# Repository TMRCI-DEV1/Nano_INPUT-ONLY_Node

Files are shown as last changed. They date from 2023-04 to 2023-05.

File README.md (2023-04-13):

# Nano_INPUT-ONLY_Node
Arduino Nano-based input only Node
capture-2023-02-14T20_02_11 532Z

Shield: [][cc-by-sa]

This work is licensed under a
[Creative Commons Attribution-ShareAlike 4.0 International License][cc-by-sa].

[][cc-by-sa]

[cc-by-sa]: http://creativecommons.org/licenses/by-sa/4.0/
[cc-by-sa-image]: https://licensebuttons.net/l/by-sa/4.0/88x31.png
[cc-by-sa-shield]: https://img.shields.io/badge/License-CC%20BY--SA%204.0-lightgrey.svg

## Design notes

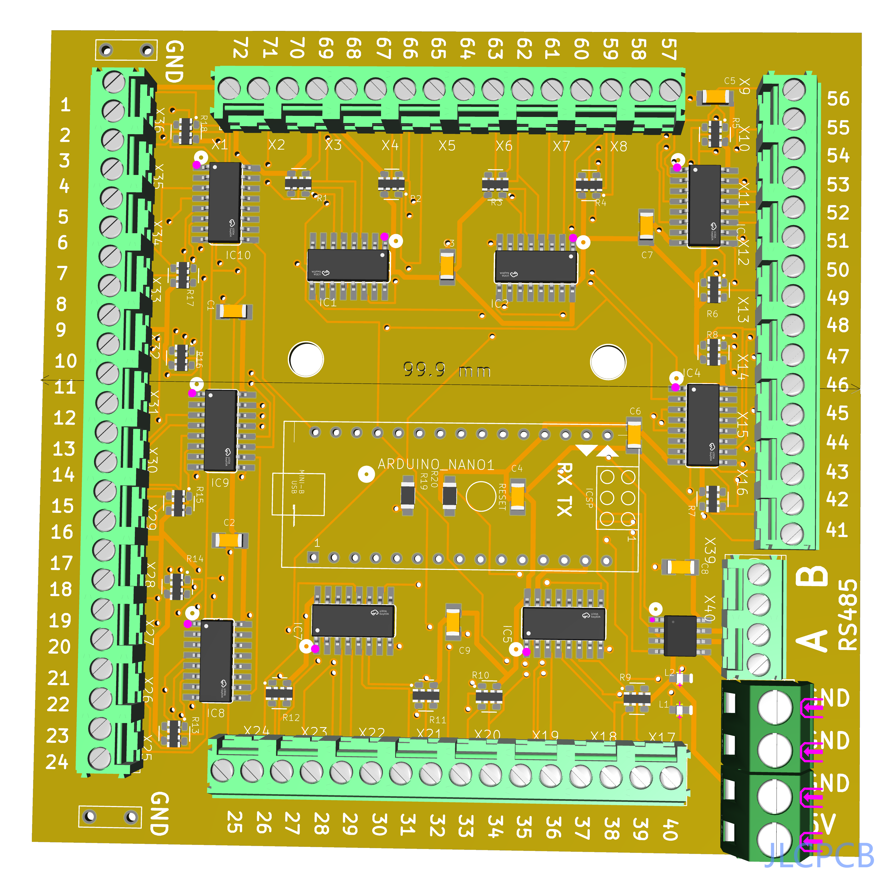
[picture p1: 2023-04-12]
KiCad/3D_Models/capture-2023-02-14T20_02_11.532Z.png

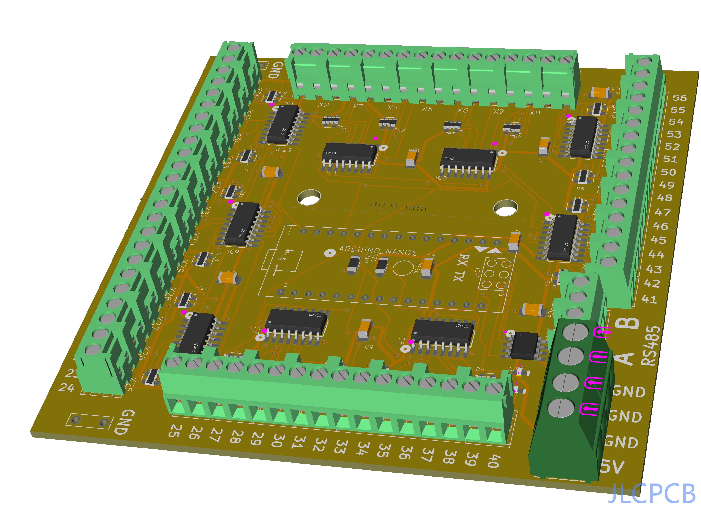
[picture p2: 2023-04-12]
KiCad/3D_Models/capture-2023-02-14T20_02_35.878Z.png

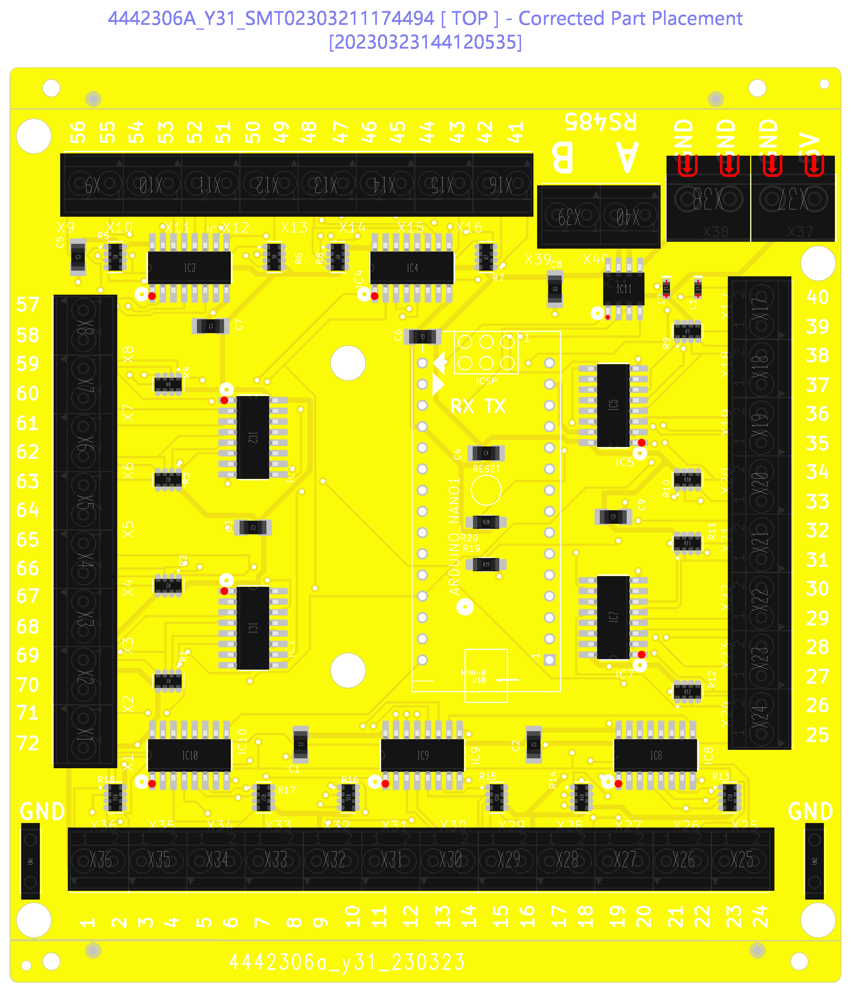
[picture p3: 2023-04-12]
KiCad/3D_Models/Produce_DanZhi.SMT_Snapshot.Top.4442306A_Y31.SMT02303211174494.png

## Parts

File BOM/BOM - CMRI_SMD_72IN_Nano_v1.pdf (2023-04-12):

Designators | Value | Footprint | Manufacturer Part Number | Quantity
C1, C2, C3, C4, C5, C6, C7, C8, C9 | 100nF | 1206 | CL31B104KBCNNNC | 9
R1, R2, R3, R4, R5, R6, R7, R8, R9, R10, R11, R12, R13, R14, R15, R16, R17, R18 | 10k | 0603 | 742C083103JP | 18 | OR USE: | RTA03-4D103JTP (https://jlcpcb.com/partdetail/Ralec-RTA034D103JTP/C102646)
R19, R20 | 1k | 1206 | 1206W4F1001T5 | 2

X1, X2, X3, X4, X5, X6, X7, X8, X9, X10, X11, X12, X13, X14, X15, X16, X17, X18, X19, X20,
X21, X22, X23, X24, X25, X26, X27, X28, X29, X30, X31, X32, X33, X34, X35, X36, X39, X40 TERMINAL_7.5X7.3MM_TM | TERMINAL_7.5X7.3MM_TM | KF350-3.5-2P | 38
X37, X38 | TERMINAL_10.16X8.1MM_TM | TERMINAL_10.16X8.1MM_TM WJ128V-5.0-2P | 2
IC1, IC2, IC3, IC4, IC5, IC7, IC8, IC9, IC10 | 74HC165D, 653 | SOIC16_150MIL | 74HC165D,653 | 9
H1, H2 | MOUNT-HOLE4.1 | 4,1 | | 2 | DNP
ARDUINO_NANO1 | | ARDUINO_NANO_HEADERS | 15Fx1-254mm | 2 | DNP | 15Fx1-254mm (https://www.electromaker.io/shop/product/254mm-01-15-pin-female-header)
IC11 | MAX485 | SOP8 | MAX485ED | 1
U$1, U$2 | Quick connect terminal Plugin | LUG-5MM | JNQ023 | 2 | | JNQ023 (https://www.lcsc.com/product-detail/Cold-pressed-Terminals_Temile-JNQ023_C499663.html)
L2 | Vcc，CHIPLED_0603, red | 0603 | LTST-C190KRKT | 1
L1 | Status，CHIPLED_0603, yellow | 0603 | LTST-C190KSKT | 1

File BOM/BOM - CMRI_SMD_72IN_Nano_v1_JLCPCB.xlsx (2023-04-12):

Comment | Designator | Footprint | JLCPCB Part #
Status，CHIPLED_0603, yellow | L1 | 0603 | C125095
100nF | C1,C2,C3,C4,C5,C6,C7,C8,C9 | 1206 | C24497
MAX485，SO08 | IC11 | SOP8 | C481667
10k | R1, R2, R3, R4, R5, R6, R7, R8, R9, R10, R11, R12, R13, R14, R15, R16, R17, R18 | 0603 | C102646 | C192513 | C2654027
74HC165D | IC1, IC2, IC3, IC4, IC5, IC7, IC8, IC9, IC10 | SOIC16_150MIL | C5613
TERMINAL_7.5X7.3MM_TM | X1,X2,X3,X4,X5,X6,X7,X8,X9,X10,X11,X12,X13,X14,X15,X16,X17,X18,X19,X20,X21,X22,X23,X24,X25,X26,X27,X28,X29,X30,X31,X32,X33,X34,X35,X36,X39,X40 | KF350-3.5-2P | C474892
Vcc，CHIPLED_0603, red | L2 | 0603 | C94869
1k | R19, R20 | 1206 | C4410
QUICK CONNECT TERMINAL | U$1,U$2 | PLUGIN | C499663
TERMINAL_10.16X8.1MM_TM | X37,X38 | TERMINAL_10.16X8.1MM_TM | C8269

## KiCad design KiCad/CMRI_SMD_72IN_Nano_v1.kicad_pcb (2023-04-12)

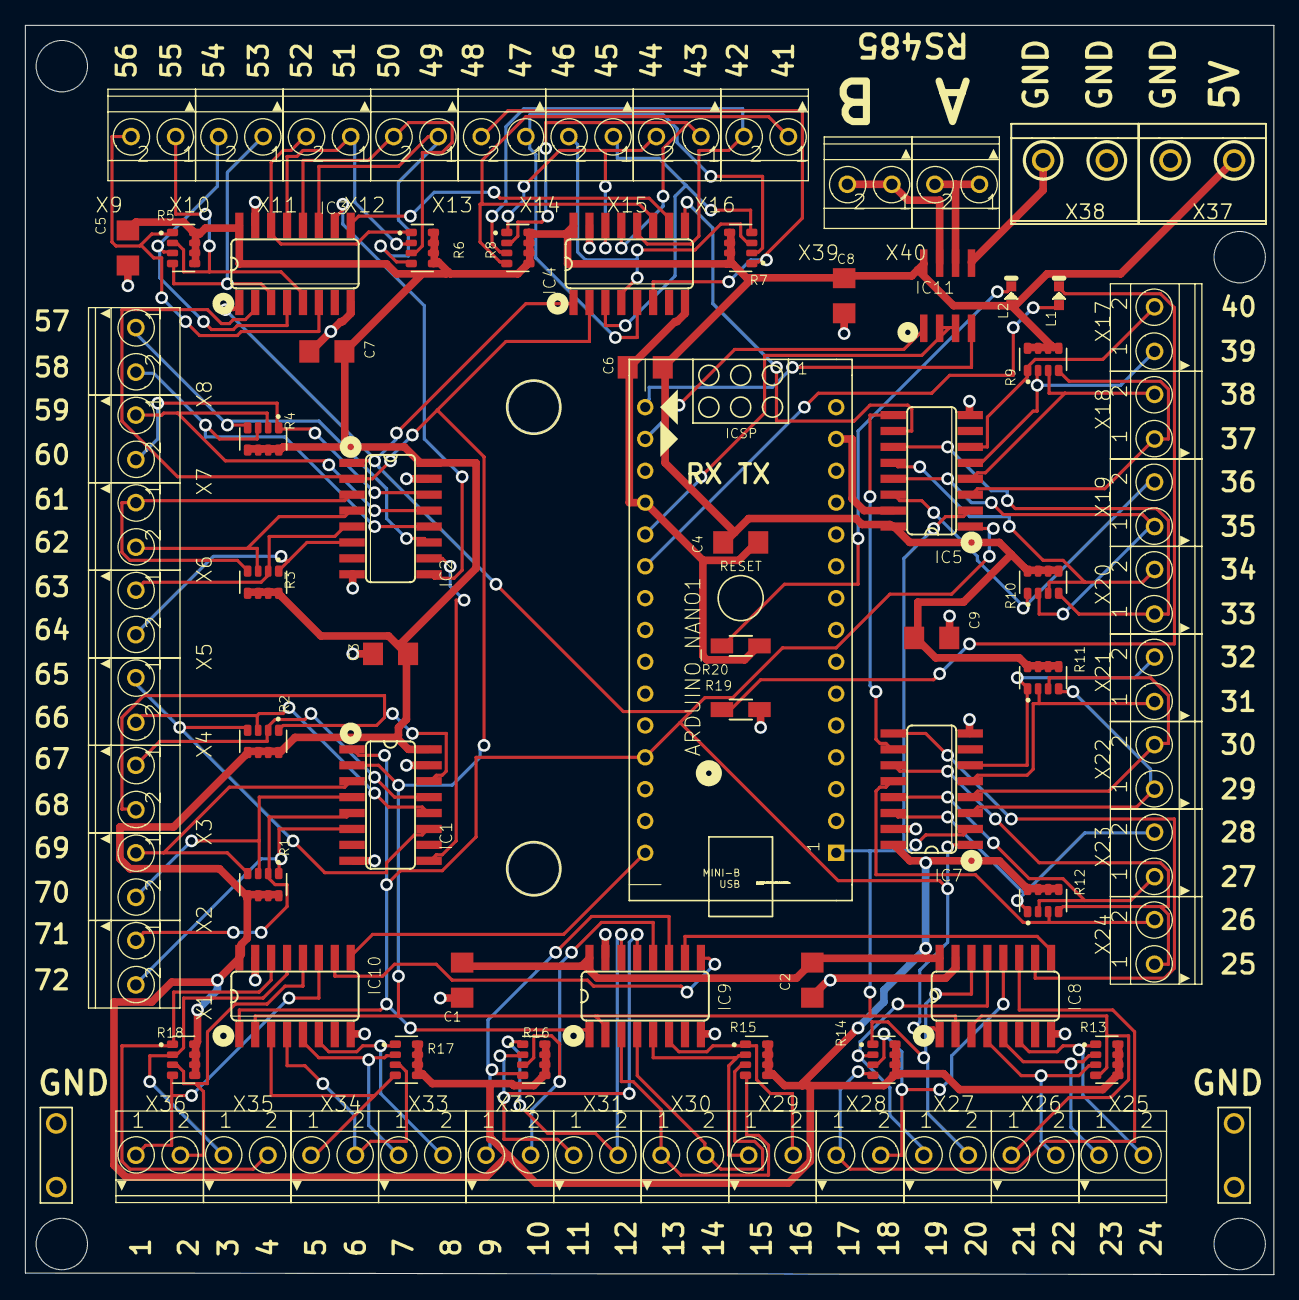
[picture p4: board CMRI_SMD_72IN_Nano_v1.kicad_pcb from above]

Board: 2 copper layers, 99.6 x 99.7 mm, 86 parts (0 on the bottom side), 93 nets.

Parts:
ARDUINO_NANO1: ARDUINO_NANO
C1, C2, C3, C4, C5, C6, C7, C8, C9: 100nF; 1206
H1, H2: MOUNT-HOLE4.1; 4,1
IC1, IC2, IC3, IC4, IC5, IC7, IC8, IC9, IC10: 74HC165D; SO16
IC11: MAX485; SO08
L1: STATUS; LED-0603
L2: Vcc; LED-0603
R1, R2, R3, R4, R5, R6, R7, R8, R9, R10, R11, R12, R13, R14, R15, R16, R17, R18: 10k; RESISTORARRAY-0603
R19, R20: 1k; R1206W
U$1, U$2: LUG-5MM
X1, X2, X3, X4, X5, X6, X7, X8, X9, X10, X11, X12, X13, X14, X15, X16, X17, X18, X19, X20, X21, X22, X23, X24, X25, X26, X27, X28, X29, X30, X31, X32, X33, X34, X35, X36, X39, X40: TERMINAL_2P_3,5MM_V2
X37, X38: W237-132

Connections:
A: IC11.6, X40.P$1, X40.P$2
B: IC11.7, X39.P$1, X39.P$2
D3: ARDUINO_NANO1.21, L1.A
GND: ARDUINO_NANO1.14, ARDUINO_NANO1.19, C1.1, C2.1, C3.1, C4.1, C5.1, C6.1, C7.1, C8.1, C9.1, IC1.8, IC1.15, IC2.8, IC2.15, IC3.8, IC3.15, IC4.8, IC4.15, IC5.8, IC5.15, IC7.8, IC7.15, IC8.8, IC8.15, IC9.8, IC9.15, IC10.8, IC10.15, IC11.5, R19.1, R20.1, U$1.P$3, U$1.P$4, U$2.P$3, U$2.P$4, X37.2, X38.1, X38.2
LATCH: ARDUINO_NANO1.27, IC1.1, IC2.1, IC3.1, IC4.1, IC5.1, IC7.1, IC8.1, IC9.1, IC10.1
unnamed: IC3.11, R6.4, X12.P$1
unnamed: IC1.9, IC2.10
unnamed: IC3.12, R6.3, X12.P$2
unnamed: IC2.9, IC3.10
unnamed: IC3.13, R6.2, X11.P$1
unnamed: IC4.11, R8.4, X16.P$1
unnamed: IC3.14, R6.1, X11.P$2
unnamed: IC4.12, R8.3, X16.P$2
unnamed: IC3.3, R5.4, X10.P$1
unnamed: IC4.13, R8.2, X15.P$1
unnamed: IC3.4, R5.3, X10.P$2
unnamed: IC4.14, R8.1, X15.P$2
unnamed: IC3.5, R5.2, X9.P$1
unnamed: IC4.3, R7.4, X14.P$1
unnamed: IC3.6, R5.1, X9.P$2
unnamed: IC4.4, R7.3, X14.P$2
unnamed: L1.C, R19.2
unnamed: IC4.5, R7.2, X13.P$1
unnamed: IC2.11, R4.4, X8.P$1
unnamed: IC4.6, R7.1, X13.P$2
unnamed: IC2.12, R4.3, X8.P$2
unnamed: IC3.9, IC4.10
unnamed: IC2.13, R4.2, X7.P$1
unnamed: IC5.11, R10.4, X20.P$1
unnamed: IC2.14, R4.1, X7.P$2
unnamed: IC5.12, R10.3, X20.P$2
unnamed: IC2.3, R3.4, X6.P$1
unnamed: IC5.13, R10.2, X19.P$1
unnamed: IC2.4, R3.3, X6.P$2
unnamed: IC5.14, R10.1, X19.P$2
unnamed: IC2.5, R3.2, X5.P$1
unnamed: IC5.3, R9.4, X18.P$1
unnamed: IC2.6, R3.1, X5.P$2
unnamed: IC5.4, R9.3, X18.P$2
unnamed: IC1.11, R2.4, X4.P$1
unnamed: IC5.5, R9.2, X17.P$1
unnamed: IC1.12, R2.3, X4.P$2
unnamed: IC5.6, R9.1, X17.P$2
unnamed: IC1.13, R2.2, X3.P$1
unnamed: IC4.9, IC5.10
unnamed: IC1.14, R2.1, X3.P$2
unnamed: IC7.11, R12.4, X24.P$1
unnamed: IC1.3, R1.4, X2.P$1
unnamed: IC7.12, R12.3, X24.P$2
unnamed: IC1.4, R1.3, X2.P$2
unnamed: IC7.13, R12.2, X23.P$1
unnamed: IC1.5, R1.2, X1.P$1
unnamed: IC7.14, R12.1, X23.P$2
unnamed: IC7.3, R11.4, X22.P$1
unnamed: IC7.4, R11.3, X22.P$2
unnamed: IC7.5, R11.2, X21.P$1
unnamed: IC7.6, R11.1, X21.P$2
unnamed: IC5.9, IC7.10
unnamed: L2.C, R20.2
unnamed: ARDUINO_NANO1.20, IC11.2, IC11.3
unnamed: IC8.11, R14.4, X28.P$1
unnamed: IC1.6, R1.1, X1.P$2
unnamed: IC8.12, R14.3, X28.P$2
unnamed: IC8.13, R14.2, X27.P$1
unnamed: IC8.14, R14.1, X27.P$2
unnamed: IC8.3, R13.4, X26.P$1
unnamed: IC8.4, R13.3, X26.P$2
unnamed: IC8.5, R13.2, X25.P$1
unnamed: IC8.6, R13.1, X25.P$2
unnamed: IC7.9, IC8.10
unnamed: IC9.11, R16.4, X32.P$1
unnamed: IC9.12, R16.3, X32.P$2
unnamed: IC9.13, R16.2, X31.P$1
unnamed: IC9.14, R16.1, X31.P$2
unnamed: IC9.3, R15.4, X30.P$1
unnamed: IC9.4, R15.3, X30.P$2
unnamed: IC9.5, R15.2, X29.P$1
unnamed: IC9.6, R15.1, X29.P$2
unnamed: IC8.9, IC9.10
unnamed: IC10.11, R18.4, X36.P$1
unnamed: IC10.12, R18.3, X36.P$2
unnamed: IC10.13, R18.2, X35.P$1
unnamed: IC10.14, R18.1, X35.P$2
unnamed: IC10.3, R17.4, X34.P$1
unnamed: IC10.4, R17.3, X34.P$2
unnamed: IC10.5, R17.2, X33.P$1
unnamed: IC10.6, R17.1, X33.P$2
unnamed: IC9.9, IC10.10
RX: ARDUINO_NANO1.17, IC11.1
SCK: ARDUINO_NANO1.1, IC1.2, IC2.2, IC3.2, IC4.2, IC5.2, IC7.2, IC8.2, IC9.2, IC10.2
SO: ARDUINO_NANO1.30, IC10.9
TX: ARDUINO_NANO1.16, IC11.4
VCC: C1.2, C2.2, C3.2, C4.2, C5.2, C6.2, C7.2, C8.2, C9.2, IC1.16, IC2.16, IC3.16, IC4.16, IC5.16, IC7.16, IC8.16, IC9.16, IC10.16, IC11.8, L2.A, R1.5, R1.6, R1.7, R1.8, R2.5, R2.6, R2.7, R2.8, R3.5, R3.6, R3.7, R3.8, R4.5, R4.6, R4.7, R4.8, R5.5, R5.6, R5.7, R5.8, R6.5, R6.6, R6.7, R6.8, R7.5, R7.6, R7.7, R7.8, R8.5, R8.6, R8.7, R8.8, R9.5, R9.6, R9.7, R9.8, R10.5, R10.6, R10.7, R10.8, R11.5, R11.6, R11.7, R11.8, R12.5, R12.6, R12.7, R12.8, R13.5, R13.6, R13.7, R13.8, R14.5, R14.6, R14.7, R14.8, R15.5, R15.6, R15.7, R15.8, R16.5, R16.6, R16.7, R16.8, R17.5, R17.6, R17.7, R17.8, R18.5, R18.6, R18.7, R18.8, X37.1

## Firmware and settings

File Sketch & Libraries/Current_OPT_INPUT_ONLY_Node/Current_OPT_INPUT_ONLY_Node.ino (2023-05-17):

/*
  Project: Arduino Nano-based CMRI Input-Only SUSIC Node (72 inputs)
  Author: Thomas Seitz (thomas.seitz@tmrci.org)
  Version: 1.0.2
  Date: 2023-05-17
  Description: A sketch for an Arduino Nano-based CMRI Input-Only custom SUSIC Node board using RS-485
*/

// Import required libraries
#include <Auto485.h>                                // Library for RS485 communication
#include <CMRI.h>                                   // Library for CMRI communication
#include <SPI.h>                                    // Library for SPI communication

const byte CMRI_ADDR = 5;                           // Define CMRI node address
const byte DE_PIN = 2;                              // Define RS485 DE and RE pins on Arduino
#define NOP __asm__ __volatile__("nop")             // "nop" assembly instruction macro

// Define pins for 74HC165
const byte LATCH_165 = 9;

Auto485 bus(DE_PIN);                                // Initialize RS485 bus transceiver
CMRI cmri(CMRI_ADDR, 72, 0, bus); // sets up a modified SMINI. 72 inputs, 0 outputs

byte last_input_state[9];                           // Define variable to store the previous state of inputs

void setup() {
  // Open the RS485 bus at 19200bps
  bus.begin(19200, SERIAL_8N2);

  // 74HC165 setup
  pinMode(LATCH_165, OUTPUT);
  digitalWrite(LATCH_165, HIGH);                    // Initialize Latch High
  SPI.begin ();                                     // Start SPI communication to control 74HC165

  // Initialize last_input_state array with current input state
  digitalWrite(LATCH_165, LOW);                     // Pulse the parallel load latch
  NOP;                                              // Wait while data loads
  NOP;
  digitalWrite(LATCH_165, HIGH);
  for (int i = 0; i < 9; i++) {
    last_input_state[i] = ~(SPI.transfer(0));
  }
}

void loop() {
  // Step 1: Process incoming messages on the CMRI bus
  cmri.process();

  // Step 2: Read the current state of the input pins
  digitalWrite(LATCH_165, LOW);                     // pulse the parallel load latch
  NOP;
  NOP;
  digitalWrite(LATCH_165, HIGH);
  byte currentInputState[9];
  for (int i = 0; i < 9; i++) {
    currentInputState[i] = ~(SPI.transfer(0));
  }

  // Step 3: If the input state has changed, update the CMRI input bytes
  if (memcmp(currentInputState, last_input_state, 9) != 0) {
    memcpy(last_input_state, currentInputState, 9);
    for (int i = 0; i < 9; i++) {
      cmri.set_byte(i, currentInputState[i]);
    }
  }
}

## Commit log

2023-04-12 Added full project
    [BOM - CMRI_SMD_72IN_Nano_v1_JLCPCB.xlsx, BOM - CMRI_SMD_72IN_Nano_v1_NEW.xlsx, BOM - DNP_CMRI_SMD_72IN_Nano_v1_JLCPCB.xls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]
2023-05-17 Update Current_OPT_INPUT_ONLY_Node.ino
    Added header

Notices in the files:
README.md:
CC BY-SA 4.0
